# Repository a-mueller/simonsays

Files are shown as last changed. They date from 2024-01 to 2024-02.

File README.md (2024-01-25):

# Simon plays songs project

This project was about creating a toy for my daughter, but mainly to use my 3D printer and to play with electronics.
I keep this here mostly for my own reference in case I have to do build another one at some point.

It basically plays a song one note at the time while lighting up the neotrellis pad, starting with only one note. Every time
the player repeats the same sequence correctly the computer plays the one more note from the song (starting again from the first)

A quick warning, I really don't know much about designing PCBs, 3D designs or embedded coding, so in the unlikely case anyone
is actually reading this please do share anything that helps me get better at this.

## Required parts

- Adafruit NeoTrellis RGB Driver PCB for 4x4 Keypad (https://www.adafruit.com/product/3954)
- Silicone Elastomer 4x4 Button Keypad - for 3mm LEDs (https://www.adafruit.com/product/1611)
- Class D amplifier, I used a cheap version of this from ebay (https://learn.adafruit.com/adafruit-pam8302-mono-2-5w-class-d-audio-amplifier, https://www.ebay.co.uk/itm/296038863752)
- A Raspberry Pi Pico (or a pico w would also work) (https://www.raspberrypi.com/products/raspberry-pi-pico/)
- A TP4056 type-C module, 18650 1A Lipo Battery Charging Board (https://www.ebay.co.uk/itm/196094318206)
- A 18650 Lipo battery, any really (https://www.ebay.co.uk/itm/225954166690?var=525048445470)
- A holder for the battery (https://www.ebay.co.uk/itm/295940408206?var=594127652418)
- Two arcade buttons (https://www.ebay.co.uk/itm/314105692727)
- Two mountable LEDs, one red one green (https://www.ebay.co.uk/itm/125364743419?var=426382146596)
- One switch button for the power switch (https://www.ebay.co.uk/itm/304538493663)
- Some JST PH 2 connectors & sockets (you will need a crimping tool if you want those connectors on the buttons / LEDs)
- A couple of 330 & 10k resistors (SMD if you make the PCB)
- One shottky Diode (https://uk.farnell.com/stmicroelectronics/1n5817/diode-schottky-1a-20v-do-41/dp/9801197)
- M2 insets & screws (https://www.amazon.co.uk/gp/product/B0B8GN63S2)
- A 4 ohm speaker (42mm screw holes distance if you don't want to modify the box) (https://www.amazon.co.uk/gp/product/B07DTFX76C)

## Schematics

I had a PCB made as there is already a lot of cables in the box and it is pretty cheap with https://jlcpcb.com - if you
go down that route I included the gerber [file](schematics/Gerber_PCB.zip), if not you will have to modify the 3d printed box to
include the mounts you need for the individual parts.

The pico is surface mounted, so are the resistors, so you want a reflow oven for that most likely.

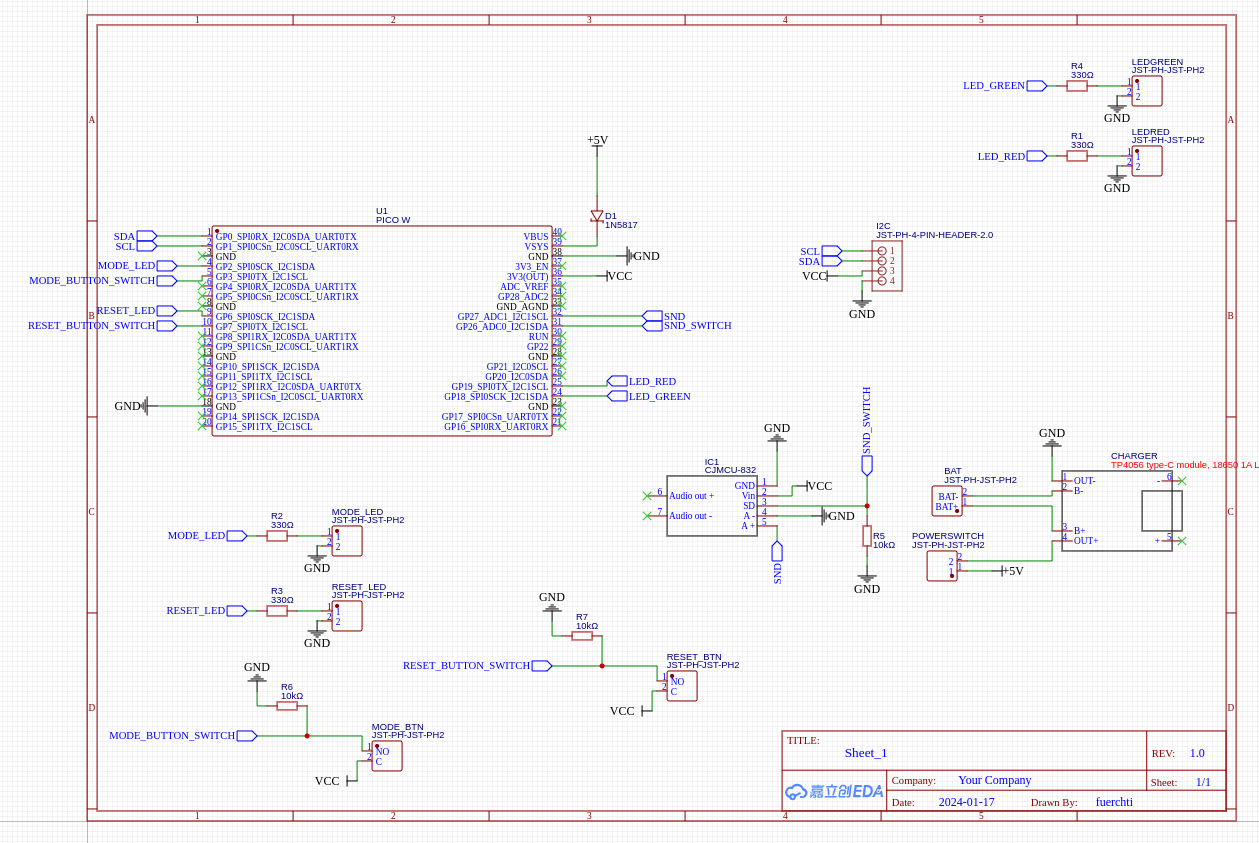
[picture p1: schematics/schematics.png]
Schematic


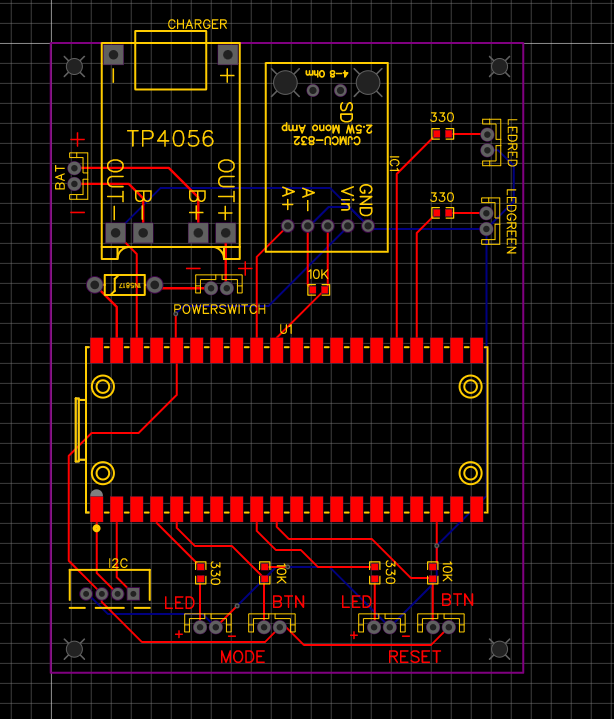
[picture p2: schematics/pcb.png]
PCB


## Connecting stuff

- Mode, there are two JST PH 2 connectors one for the button's led and one for the button. It is used to switch between song selection and playing modes
- Reset, again two JST PH 2 connectors one for the button's led and one for the button. It is not used to reset anything, but to toggle the sound on / off.
- POWERSWITCH, connect to the middle switch button. Cuts the power to the PCB
- BAT, obviously the battery holder that holds the 18650 Lipo battery
- LEDGREEN, connect to the green LED, which indicates it is the users turn to press the buttons
- LEDRED, connect to the red LED, indicating it is the computers turn
- I2C, connect to the NeoTrellis RGB Driver board

## 3D printing the box

There is a [FreeCAD](printedParts/simon-says-box.FCStd) file if you want to modify it for different parts or if you don't want to have the PCB made.
There is also the STL files in the ./printedParts folder in case no modification is needed. It is pretty obvious where the m2 insets should get added.

## Building the U2F

Make sure you have the pico C sdk setup (https://github.com/raspberrypi/pico-sdk) and the environment variables exported.
This was written against version `1.5.1` so this might need some rework if the current version is far higher than this.

### Clone the repo & dependencies
```shell
git clone git@github.com:a-mueller/simonsays.git
cd simonsays
git submodule init
git submodule update
```

### Build
```shell
mkdir build
cd build
cmake ..
```

use the resulting u2f file and copy it over to the board

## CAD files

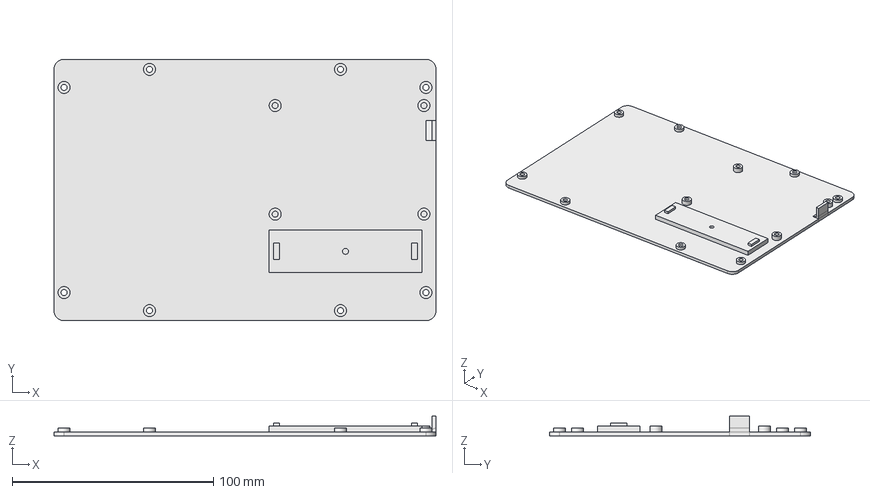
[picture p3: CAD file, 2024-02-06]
printedParts/simon-says-box.FCStd
190.0 x 130.0 x 9.80 mm

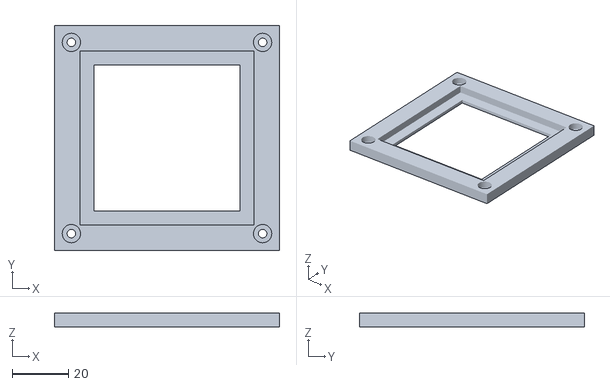
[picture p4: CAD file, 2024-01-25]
printedParts/simon-says-box-trellis_holder.stl
80.0 x 80.0 x 5.00

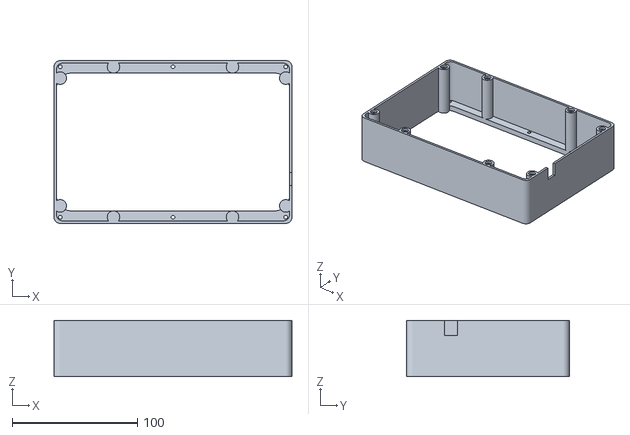
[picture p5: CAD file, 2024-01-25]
printedParts/simon-says-box-wall.stl
190.0 x 130.0 x 45.0

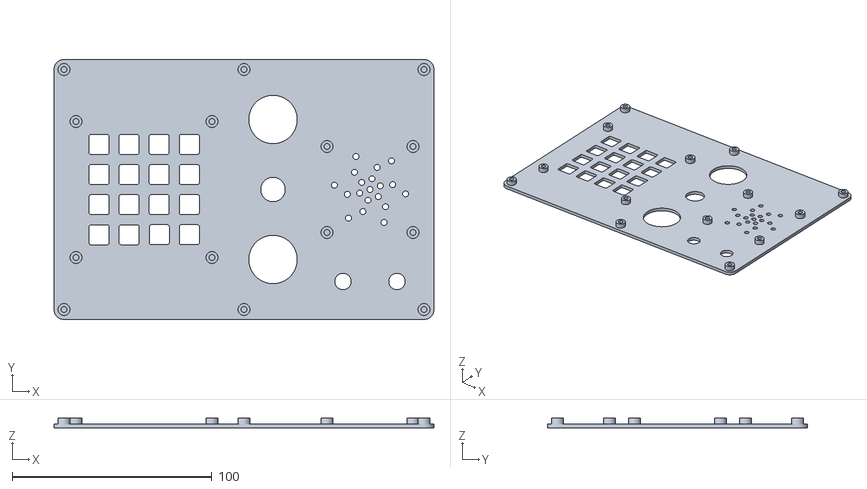
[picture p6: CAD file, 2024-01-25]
printedParts/simon-says-box-top-plate.stl
190.0 x 130.0 x 5.00

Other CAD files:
printedParts/simon-says-box-bottom_plate.stl

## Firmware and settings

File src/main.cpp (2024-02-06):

#include <neotrellis.hpp>
// #include <pico_tone.hpp>

#include "pico/stdlib.h"
#include <stdio.h>
#include <sys/stat.h>

#include "io.hpp"
#include "config.hpp"
#include "game.hpp"
#include "keypad_map.hpp"
#include "melody_player.hpp"
#include "songs.hpp"


enum Mode {
    SONG_SELECTION,
    TURN_USER,
    TURN_COMPUTER,
    TURN_INCORRECT,
    TURN_FINISH
};

enum SoundState {
    ON, OFF
};

Mode mode = SONG_SELECTION;
SoundState soundState = ON;

Game game;
MelodyPlayer melodyPlayer;

NeoTrellis *trellisPtr;
Tone *myPlayerPtr;


void keypad_handler(uint8_t key, Keypad::Edge edge);


int main() {
    stdio_init_all();

    /* Init the trellis library */
    NeoTrellis trellis(PICO_I2C, PIN_SDA, PIN_SCL);
    trellis.init();
    trellis.keypad.set_callback(keypad_handler);
    trellisPtr = &trellis;

    /* Init the sound library */
    Tone myPlayer(PIN_SOUND_OUT, 50, 0, 20, 0, 20, 0, 10);
    myPlayer.init(TONE_NON_BLOCKING, false);
    myPlayerPtr = &myPlayer;

    /* Setup the button and led pins */
    init_io();

    /* Indicate to the user that we are starting up */
    indicate_startup(&trellis);


    /* Make sure we have a song loaded in case the user doesn't select one */
    game.init(happyBirthday, HAPPY_BIRTHDAY_LENGTH);

    /* Start in song selection mode */
    show_song_selection_mode(&trellis);

    while (true) {
        trellis.keypad.update();

        if (gpio_get(PIN_BTN_SONG_SELECT)) {
            // we want to switch mode
            if (mode != SONG_SELECTION) {
                mode = SONG_SELECTION;
                // turn the led on
                show_song_selection_mode(&trellis);
            } else {
                melodyPlayer.stop(&myPlayer);
                melodyPlayer.reset();

                mode = TURN_COMPUTER;
                game.reset();
                // turn the leds and trellis off
                show_computer_turn();
                all_trellis_off(&trellis);
            }

            // wait till the button is up again before we go on with the loop
            while (gpio_get(PIN_BTN_SONG_SELECT)) {
                sleep_ms(10);
            }
        } else if (gpio_get(PIN_BTN_SOUND_TOGGLE)) {
            if (soundState == ON) {
                switch_sound(false);
                soundState = OFF;
            } else {
                switch_sound(true);
                soundState = ON;
            }
            // wait till the button is up again before we go on with the loop
            while (gpio_get(PIN_BTN_SOUND_TOGGLE)) {
                sleep_ms(10);
            }
        } else {
            // game play
            if (mode == TURN_INCORRECT) {
                show_trellis(&trellis);

                // make a red X
                show_user_failed_pad(&trellis);

                // reset game
                game.reset();

                sleep_ms(1000);
                all_trellis_off(&trellis);

                mode = TURN_COMPUTER;
                show_computer_turn();
            } else if (mode == TURN_FINISH) {
                show_trellis(&trellis);

                // make a green tick
                show_user_success_pad(&trellis);

                // reset game
                game.reset();
                mode = TURN_COMPUTER;

                sleep_ms(2000);
                all_trellis_off(&trellis);
                show_computer_turn();
            } else if (mode == TURN_COMPUTER) {
                if (!game.reachedTargetPosition()) {
                    game.runComputerTurn(&trellis, &myPlayer);
                } else {
                    mode = TURN_USER;
                    show_user_turn();
                    game.swichTurn(false);
                }
            } else if (mode == TURN_USER) {
                show_trellis(&trellis);

                if (game.reachedTargetPosition()) {
                    mode = TURN_COMPUTER;
                    game.swichTurn(true);
                    show_computer_turn();
                    sleep_ms(500);
                }
            } else if (mode == SONG_SELECTION) {
                show_trellis(&trellis);
                melodyPlayer.loop(&myPlayer);
            }

            sleep_ms(50);
        }
    }
}


void keypad_handler(uint8_t key, Keypad::Edge edge) {
    if (edge == Keypad::Edge::RISING) {
        if (mode == TURN_USER) {
            const int colour = KEYPAD_POS_TO_COLOUR.at(key);
            const int correctNote = game.noteAtNextPosition();

            if (NOTE_TO_KEYPAD_POS.at(correctNote) == key) {
                myPlayerPtr->tone(correctNote);
            } else {
                myPlayerPtr->tone(KEYPAD_POS_TO_DEFAULT_NOTE.at(key));
            }

            trellisPtr->pixels.set(key, colour);
        } else if (mode == SONG_SELECTION) {
            all_trellis_off(trellisPtr, false);
            trellisPtr->pixels.set(key, COLOR_WHITE);
            if (key == 0) {
                game.init(happyBirthday, HAPPY_BIRTHDAY_LENGTH);
                melodyPlayer.init(happyBirthday, HAPPY_BIRTHDAY_LENGTH);
                melodyPlayer.start();
            } else if (key == 1) {
                game.init(wheelsOnTheBus, WHEELS_ON_THE_BUS_LENGTH);
                melodyPlayer.init(wheelsOnTheBus, WHEELS_ON_THE_BUS_LENGTH);
                melodyPlayer.start();
            } else if (key == 2) {
                game.init(fiveLittleDucks, FIVE_LITTLE_DUCKS_LENGTH);
                melodyPlayer.init(fiveLittleDucks, FIVE_LITTLE_DUCKS_LENGTH);
                melodyPlayer.start();
            } else if (key == 3) {
                game.init(auldLangSyne, AULD_LANG_SYNE_LENGTH);
                melodyPlayer.init(auldLangSyne, AULD_LANG_SYNE_LENGTH);
                melodyPlayer.start();
            }
        }
    } else {
        if (mode == TURN_USER) {
            trellisPtr->pixels.set(key, COLOR_BLACK);
            myPlayerPtr->stop();

            // check if that was actually correct
            const int correct_note = game.noteAtNextPosition();
            const uint8_t correct_key = NOTE_TO_KEYPAD_POS.at(correct_note);

            if (correct_key != key) {
                mode = TURN_INCORRECT;
            } else {
                game.advanceToNextNote();
                if (game.reachedEnd()) {
                    mode = TURN_FINISH;
                }
            }
        } else if (mode == SONG_SELECTION) {
            show_song_selection_mode(trellisPtr, false);
            melodyPlayer.stop(myPlayerPtr);
            // myPlayerPtr->stop();
        }
    }
}

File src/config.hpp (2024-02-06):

//
// Created by abmue on 24/01/24.
//

#ifndef CONFIG_HPP
#define CONFIG_HPP

#define PICO_I2C i2c0
#define PIN_SDA 0
#define PIN_SCL 1

#define PIN_SOUND_OUT 27
// if the Shutdown pin from the D-class amplifier board is connected, it should be pulled to ground by default (off)
// We will set this pin high before playing sound, so make sure there is nothing else on this pin in case you didn't connect it
#define PIN_SOUND_SWITCH 26

#define PIN_LED_USER_TURN 18
#define PIN_LED_COMPUTER_TURN 19

#define PIN_BTN_LED_SONG_SELECT 2
#define PIN_BTN_SONG_SELECT 3
// #define PIN_BTN_LED_SONG_SELECT 5
// #define PIN_BTN_SONG_SELECT 4

#define PIN_BTN_LED_SOUND_TOGGLE 6
#define PIN_BTN_SOUND_TOGGLE 7

// It seems that if you don't wait a while after setting the neopixels they behave strangely (especially the one at 0)
#define TRELLIS_UPDATE_DELAY_MS 20

#endif //CONFIG_HPP

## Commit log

2024-01-25 adds sound on / off switch and comments
2024-01-25 adds turn leds
2024-01-25 adds some documentation
    [simon-says-box-bottom_plate.stl, simon-says-box-top-plate.stl, simon-says-box-trellis_holder.stl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]
2024-02-06 adds song preview
    [simon-says-box-bottom_plate.stl, simon-says-box.FCStd]
2024-02-06 fixes five little dugs and adds auld lang syne
    [io.cpp, main.cpp, songs.hpp]
